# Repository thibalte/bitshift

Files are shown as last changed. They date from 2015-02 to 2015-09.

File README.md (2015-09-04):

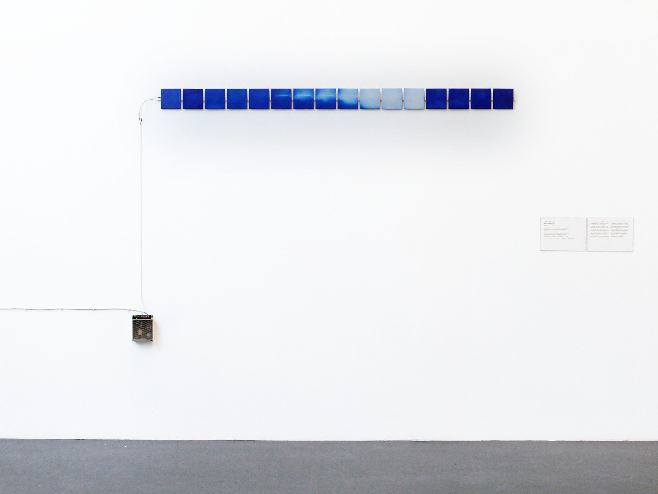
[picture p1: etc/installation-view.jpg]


# Bitshift

Thibault Brevet, _Bitshift_, 2015

16 printed circuit boards (10x10cm PCB, white soldermask), blue thermochromatic pigment, power supply.

Bitshift explores the physical manifestation of a digital signal bit shifting along autonomous modules. Each module integrates electronic on the back-side able to register an input signal. When triggered, each module switches on an integrated heating pattern traced on its front-side. When reaching 37°c, the blue thermochromatic pigment turns transparent, revealing the white undercoating. After executing the heating sequence, a pulse is sent to the next module. The pigment eventually fades back to blue as it cools down.

On view during [Re-programmed Art: An Open Manifesto](http://www.reprogrammed-art.cc/) at Swiss Institute in Milan, IT.

### Technical details

PCBs have been sent to the fab house specifying a white soldermask, 35um copper thickness, all rest is standard. PCBs heating panel is designed to act as a 4 Ohm resistor, with a 12V power supply it sinks 3A and dissipates about 36W and warms 20°C above a target 21°C ambient temperature. The thermochromatic pigment used has a threshold temperature of 37°C, in line with the heating panel max temperature of 41°C.

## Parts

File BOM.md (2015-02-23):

# component list per module

| pieces | part reference | description | element14 part number
-------- | -------------- | ----------- | ---------------------
| 1 | MIC5205 | 5V voltage regulator | 1556768
| 1 | ATTiny 45/85 | AVR microchip | 1288353
| 1 | FDS6630A | n-channel power mosfet | 9845240
| 3 | | 0805 330 Ohm resistor | 2447638RL
| 2 | | 0805 10k Ohm resistor | 9332391
| 1 | | 0805 1M Ohm resistor | 2447596
| 1 | | 0805 green led | 1318243
| 1 | | 0805 red led | 2099236
| 1 | | 0805 blue led | 2217980
| 1 | | 0805 0.1uF ceramic capacitor | 1856468
| 1 | | 0805 1uF ceramic capacitor | 1816837
| 2 | BG301-06-A-0540-L-B | male smd header 6-pin | 2084270
| 1 | BG300-06-A-L-A | female smd header 6-pin | 2084265

Top coat is made with thermochromatic pigment mixed with a clear UV-resistaat acrylic binder. Sourced at Sparkfun, reference COM-11558.

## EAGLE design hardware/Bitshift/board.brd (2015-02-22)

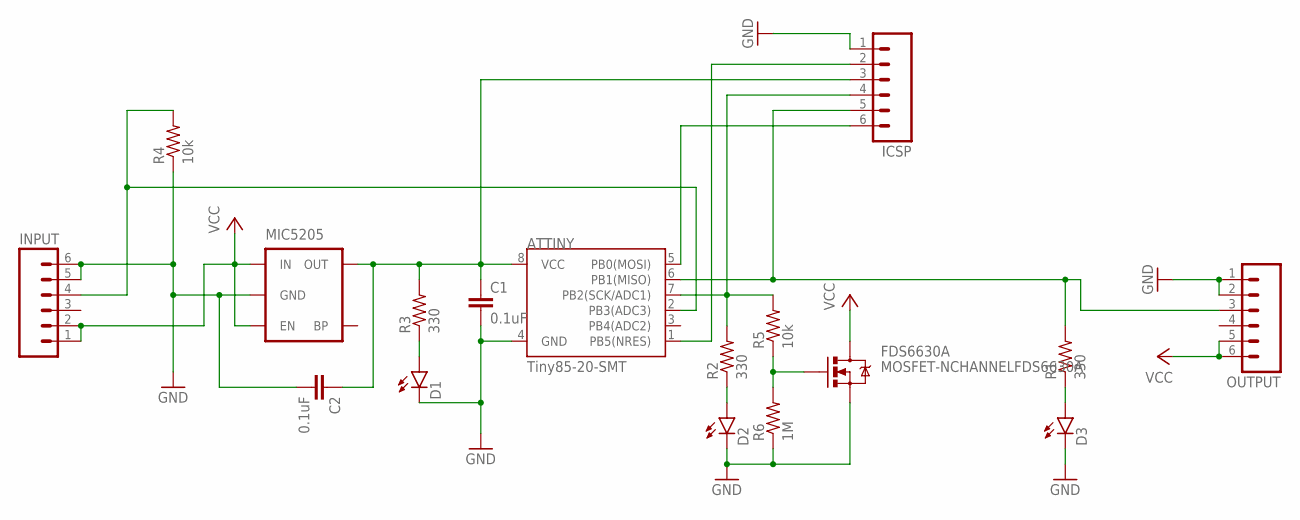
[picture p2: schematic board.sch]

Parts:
ATTINY: Tiny85-20-SMT; SO08-EIAJ
C1, C2: 0.1uF; 0805
D1, D2, D3: LED0603; LED-0603
FDS6630A: MOSFET-NCHANNELFDS6630A; SO08
ICSP: M06SMD-FEMALE-V2; 1X06-SMD-FEMALE-V2
INPUT: M06SMD-FEMALE-V2; 1X06-SMD-FEMALE-V2
MIC5205: MIC52055V; SOT23-5
OUTPUT: M06SMD-FEMALE-V2; 1X06-SMD-FEMALE-V2
R1, R2, R3: 330; 0603-RES
R4: 10k; 0603-RES
R5: 10k; 0805
R6: 1M; 0805

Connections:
GND: ATTINY.4 (GND), C1.2, C2.2, D1.C, D2.C, D3.C, FDS6630A.1 (S), FDS6630A.2 (S), FDS6630A.3 (S), ICSP.1, INPUT.5, INPUT.6, MIC5205.2 (GND), OUTPUT.1, OUTPUT.2, R4.1, R6.1
unnamed: D1.A, R3.1
unnamed: D2.A, R2.1
unnamed: D3.A, R1.1
unnamed: ATTINY.8 (VCC), C1.1, C2.1, ICSP.3, MIC5205.5 (OUT), R3.2
unnamed: ATTINY.2 (PB3(ADC3)), INPUT.4, R4.2
unnamed: ATTINY.6 (PB1(MISO)), ICSP.5, OUTPUT.3, R1.2
unnamed: ATTINY.5 (PB0(MOSI)), ICSP.6
unnamed: FDS6630A.4 (G), R5.1, R6.2
unnamed: ATTINY.7 (PB2(SCK/ADC1)), ICSP.4, R2.2, R5.2
unnamed: ATTINY.1 (PB5(NRES)), ICSP.2
VCC: FDS6630A.5 (D), FDS6630A.6 (D), FDS6630A.7 (D), FDS6630A.8 (D), INPUT.1, INPUT.2, MIC5205.1 (IN), MIC5205.3 (EN), OUTPUT.5, OUTPUT.6

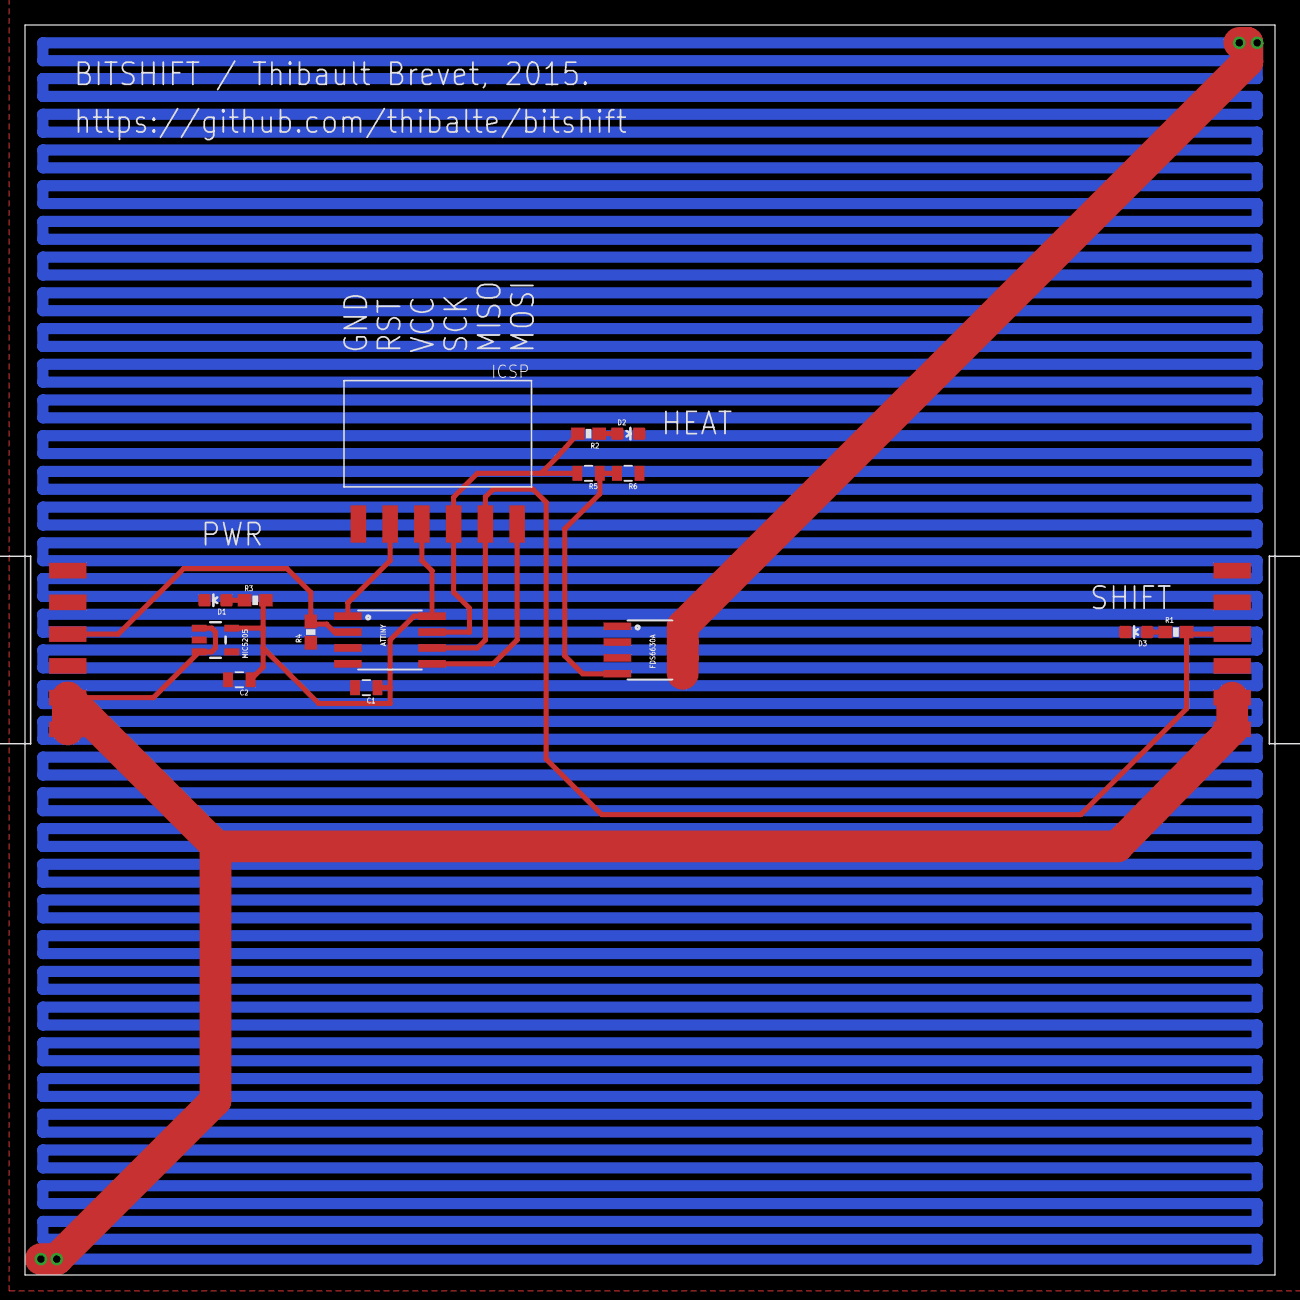
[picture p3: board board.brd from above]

Board: 2 copper layers, 100.0 x 100.0 mm, 17 parts (0 on the bottom side), 12 nets.

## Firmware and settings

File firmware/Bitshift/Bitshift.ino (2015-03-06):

//
// BITSHIFT
// Thibault Brevet, 2015
// release under the MIT license
//
// flash via Arduino IDE on ATTiny45/85 chips
//

int shift = 1; // signal out
int heat = 2; // mosfet control

void setup()
{
  pinMode(shift, OUTPUT);
  pinMode(heat, OUTPUT);
}

void loop()
{

    // first turn on HEAT at maximum to reach temperature for specified time
    digitalWrite(heat, HIGH);
    delay(1000);
    digitalWrite(heat, LOW);

    // then forward SIGNAL for specififed time
    digitalWrite(shift, HIGH);
    delay(1000);
    digitalWrite(shift, LOW);
}

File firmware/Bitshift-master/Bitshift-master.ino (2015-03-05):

//
// BITSHIFT
// Thibault Brevet, 2015
// release under the MIT license
//
// flash via Arduino IDE on ATTiny45/85 chips
//

int in = 3; // signal in
int shift = 1; // signal out
int heat = 2; // mosfet control

int heatTime = 15000; // how long we heat the panel

int wait = 5000;
int sigTime = 500; // how long we keep the OUT signal pulled high

int masterWait = 380;

void setup()
{
  pinMode(in, INPUT);
  pinMode(shift, OUTPUT);
  pinMode(heat, OUTPUT);
}

void loop()
{

  // first turn on HEAT at maximum to reach temperature for specified time
  digitalWrite(heat, HIGH);
  delay(heatTime);
  digitalWrite(heat, LOW);
  
  // wait some time before shifting to next board
  delay(wait);

  // then forward SIGNAL for specififed time
  digitalWrite(shift, HIGH);
  delay(sigTime);
  digitalWrite(shift, LOW);
  delay(100);
  
  // do a loop because max val of delay() is 32767ms
  for (int i=0; i<masterWait; i++){
    delay(1000);
  }

}

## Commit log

2015-02-20 added eagle files
    [board.brd, board.sch]
2015-02-20 added firmware, added pull-down resistor for IN signal
2015-02-22 added BOM, added ICSP header to board
    [board.sch]
2015-02-22 changed BOM into MD table
2015-02-22 removed url in BOM
2015-02-22 added connectors to BOM
2015-02-22 added decoupling cap for voltage regulator in BOM
    [board.brd, board.sch]
2015-02-22 moved things around
    [board.brd, board.sch]
2015-02-22 exported gerber files
    [board.brd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]
2015-02-23 cleanup board files
2015-03-05 added firmware for master board with intervallometer trigger pulse

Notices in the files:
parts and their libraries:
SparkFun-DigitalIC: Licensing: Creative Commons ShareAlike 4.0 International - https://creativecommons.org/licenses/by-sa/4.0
